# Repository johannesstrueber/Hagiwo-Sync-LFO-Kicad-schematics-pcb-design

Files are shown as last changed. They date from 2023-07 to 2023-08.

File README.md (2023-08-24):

# HAGIWO's SYNC LFO Eurorack Module<br/> Work in Progress Schematics, PCBs, and Design Files 

In this repository, I digitalized HAGIWOs sketched schematics in Kicad and then created PCBs for the circuit and a front panel. I also created two design files. The first is for matching the drill holes of the panel with the placed components. The second is for labeling the components on the silkscreen layer of the panel.

***This is a work-in-progress project. Actually, this is my first layout. Take nothing for granted. The second revision is produced.*** 
<br/>
<br/>
**TODO** <br/>
<ul>
<li>Physical solution for wrong pot direction (currently software solution)</li>
<li>code for second inverted output (is in WIP status)</li>
<li>GND planes</li>
</ul>
<br/>

**Here are the in- and outputs. To get a idea of the module**
- Knob 1: AMP – amplifier control. The output voltage is set between 0 and 5 volts. 
- Knob 2: PHASE – phase control sets the phase
- Knob 3: waveform control 
- Knob 4: MOD – internal modulation, creates complex waveforms 
- Input 1:  CLK – clock in
- Output 1: OUT – output
- Output 2: INV – inverted output
<br/>

**KICAD Notes**
 - design_placement.svg is placed on layer USER 8
 - circuit layout is generated by the freerouting plugin
<br/>

**BOM**
|ID |Identifier |Footprint |Amount|Description |
|---|---|---|---|---|
|1  |D4,D3 |LED_D3.0mm |2 |LED |
|2  |RV3-FORM1,RV2-PHASE1,RV4-MOD1,RV1-AMP1|Potentiometer_Alps_RK09K_Single_Vertical |4 |R_Potentiometer_US|
|3  |J1 |Jack_3.5mm_QingPu_WQP-PJ398SM_Vertical_CircularHoles|1 |CLOCK IN |
|4  |J3 |Jack_3.5mm_QingPu_WQP-PJ398SM_Vertical_CircularHoles|1 |INV |
|5  |J2 |Jack_3.5mm_QingPu_WQP-PJ398SM_Vertical_CircularHoles|1 |OUT |
|6  |R10,R4,R6,R7,R1,R5 |R_Axial_DIN0204_L3.6mm_D1.6mm_P2.54mm_Vertical |6 |R 470 |
|7  |C4,C1,C3,C2 |C_Disc_D4.3mm_W1.9mm_P5.00mm |4 |C 220pF |
|8  |D2,D1 |D_DO-35_SOD27_P7.62mm_Horizontal |2 |BAT43 |
|9  |R9,R8 |R_Axial_DIN0204_L3.6mm_D1.6mm_P2.54mm_Vertical |2 |R 33K |
|10 |J4 |IDC-Header_2x05_P2.54mm_Vertical |1 |Connector_02x05 |
|11 |R3 |R_Axial_DIN0204_L3.6mm_D1.6mm_P2.54mm_Vertical |1 |R 100K |
|12 |C6,C5 |CP_Radial_D5.0mm_P2.50mm |2 |C 4.7 µF |
|13 |A1 |Arduino_Nano |1 |Arduino_Nano |
|14 |R2 |R_Axial_DIN0204_L3.6mm_D1.6mm_P2.54mm_Vertical |1 |R 1K |

**CHANGELOG** <br/>
<br/>

**rev 0.2.1** <br/>
<ul>
<li>I adjusted the drilling diameter to 7.2mm to fit the threads of some potentiometers, e.g., t18. The previous front panel was made for rv09 potentiometers, which don't have a larger thread drilling.</li>
<li>the main pcb stays the same as 0.2.0</li>
</ul>
<br/>

**rev 0.2** <br/>
<ul>
<li> !!! changed pin order on connector </li>
<li> 10 pin connector instead of 16 pin</li>
<li> add missing 33k resistor for LED </li>
<li> resistors and capacitors now have values </li>
<li> larger gap setting for disc capacitors </li>
<li> code wrong direction potis</li>
<li> new design to match other upcoming modules </li>
<li> second output INV - inverted 
</ul>
<br/>

**rev 0.1** <br/>
<ul>
<li>first layout PRODUCED and working</li>
</ul>
<br/>

Hence, this is only trying to put HAGIWOs circuit into Kicad to create a PCB. You can find more information about the layout and functionality [ + here](https://note.com/solder_state/n/n4c600f2431c3) 
<br/>
<br/>

**Original Design and Code by HAGIWO** 
- [HAGIWO – note.com](https://note.com/solder_state)
- [HAGIWO – Twitter](https://twitter.com/HAGIWO1)
<br/>

**Fonts**
- [Rocko – Casady & Greene](https://moorstation.org/typoasis/designers/casady_greene/r_z.htm)
- [Tiny – Jack Halten Fahnestock](https://velvetyne.fr/fonts/tiny/)
<br/>

**Pictures of the produced rev 0.2**
<br/>
<br/>
front
<br/>
back
<br/>
side

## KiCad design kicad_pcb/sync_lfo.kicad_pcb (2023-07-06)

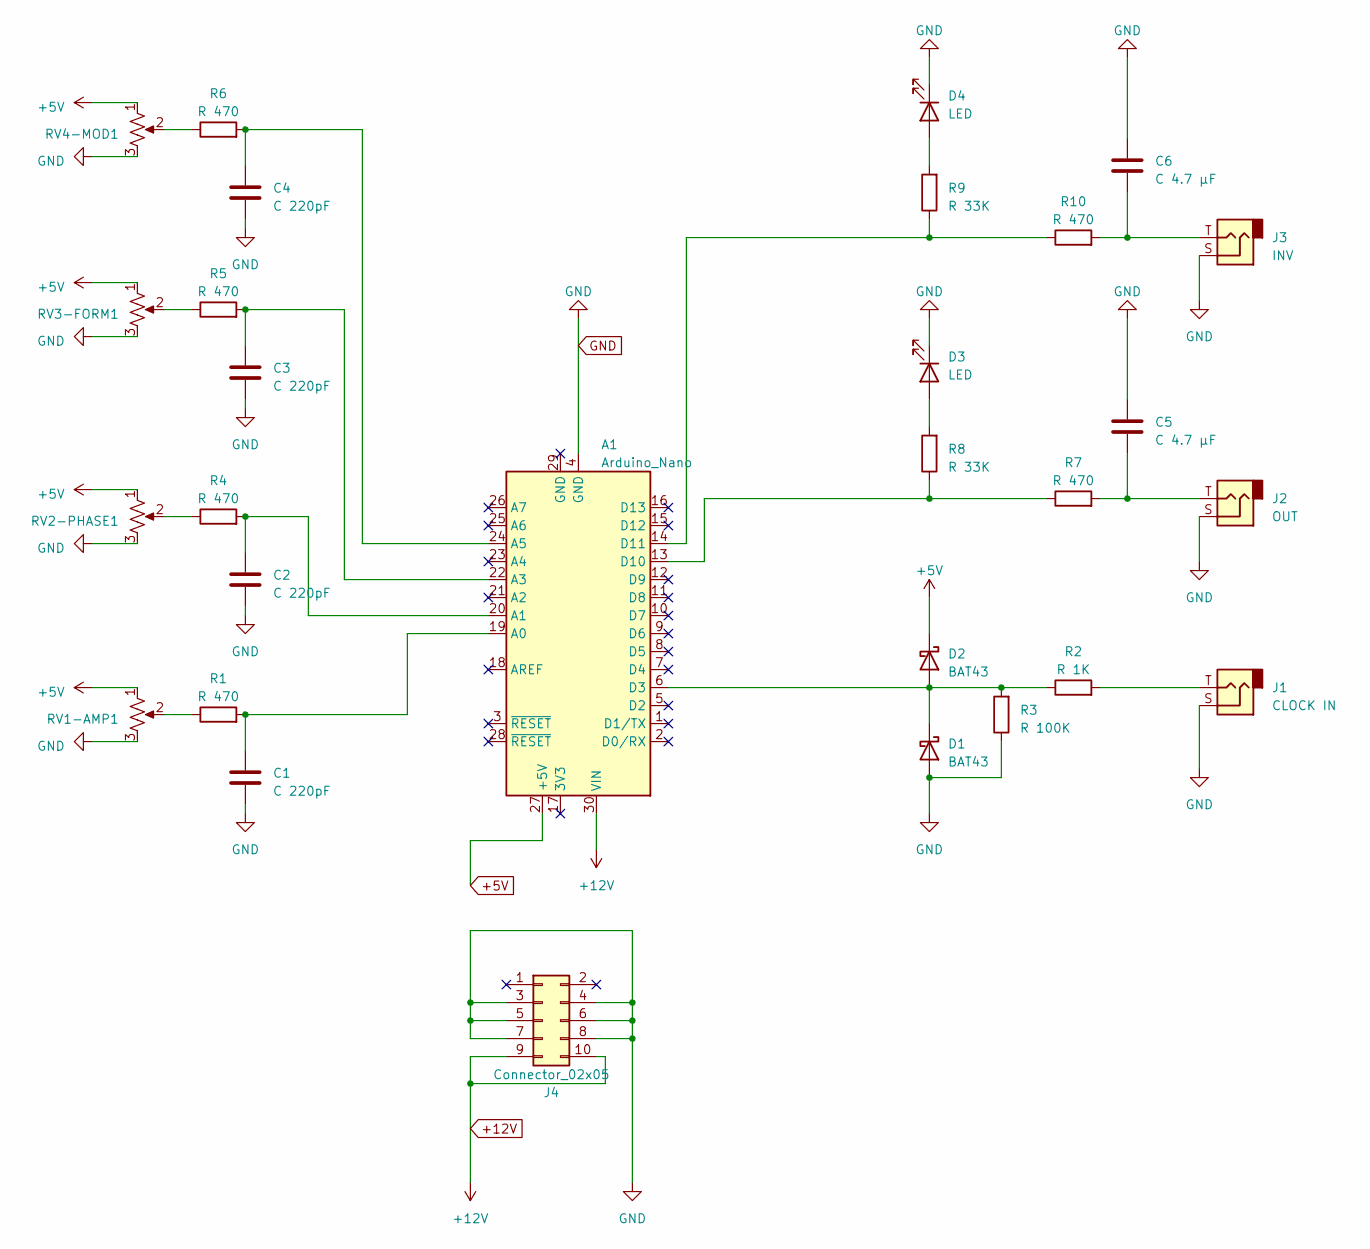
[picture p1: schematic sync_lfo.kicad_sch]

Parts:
A1: Arduino_Nano
C1, C2, C3, C4: C 220pF; C_Disc_D4.3mm_W1.9mm_P5.00mm
C5, C6: C 4.7 µF; C_Radial_D5.0mm_H11.0mm_P2.00mm
D1, D2: BAT43; D_DO-35_SOD27_P7.62mm_Horizontal
D3, D4: LED; LED_D3.0mm
J1: CLOCK IN; Jack_3.5mm_QingPu_WQP-PJ398SM_Vertical_CircularHoles
J2: OUT; Jack_3.5mm_QingPu_WQP-PJ398SM_Vertical_CircularHoles
J3: INV; Jack_3.5mm_QingPu_WQP-PJ398SM_Vertical_CircularHoles
J4: Connector_02x05; IDC-Header_2x05_P2.54mm_Vertical
R1, R4, R5, R6, R7, R10: R 470; R_Axial_DIN0204_L3.6mm_D1.6mm_P2.54mm_Vertical
R2: R 1K; R_Axial_DIN0204_L3.6mm_D1.6mm_P2.54mm_Vertical
R3: R 100K; R_Axial_DIN0204_L3.6mm_D1.6mm_P2.54mm_Vertical
R8, R9: R 33K; R_Axial_DIN0204_L3.6mm_D1.6mm_P2.54mm_Vertical
RV1-AMP1, RV2-PHASE1, RV3-FORM1, RV4-MOD1: R_Potentiometer_US; Potentiometer_Alps_RK09K_Single_Vertical

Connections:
+5V: A1.27 (+5V), D2.1 (K), RV1-AMP1.1, RV2-PHASE1.1, RV3-FORM1.1, RV4-MOD1.1
+12V: A1.30 (VIN), J4.9, J4.10
GND: A1.4 (GND), C1.2, C2.2, C3.2, C4.2, C5.1, C6.1, D1.2 (A), D3.1 (K), D4.1 (K), J1.S, J2.S, J3.S, J4.3, J4.4, J4.5, J4.6, J4.7, J4.8, R3.1, RV1-AMP1.3, RV2-PHASE1.3, RV3-FORM1.3, RV4-MOD1.3
unnamed: A1.19 (A0), C1.1, R1.2
unnamed: A1.20 (A1), C2.1, R4.2
unnamed: A1.22 (A3), C3.1, R5.2
unnamed: A1.24 (A5), C4.1, R6.2
unnamed: A1.6 (D3), D1.1 (K), D2.2 (A), R2.1, R3.2
unnamed: A1.13 (D10), R7.1, R8.1
unnamed: A1.14 (D11), R9.1, R10.1
unnamed: C5.2, J2.T, R7.2
unnamed: C6.2, J3.T, R10.2
unnamed: D3.2 (A), R8.2
unnamed: D4.2 (A), R9.2
unnamed: J1.T, R2.2
unnamed: R1.1, RV1-AMP1.2
unnamed: R4.1, RV2-PHASE1.2
unnamed: R5.1, RV3-FORM1.2
unnamed: R6.1, RV4-MOD1.2

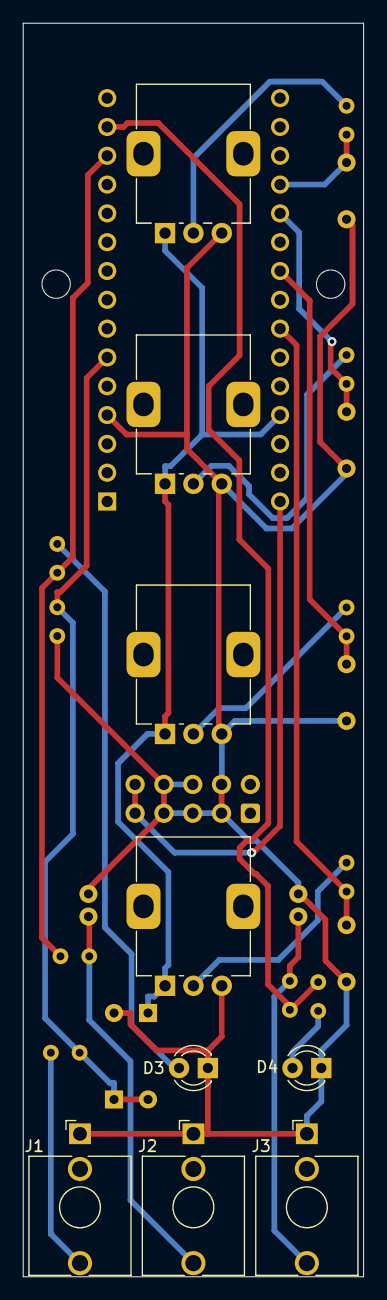
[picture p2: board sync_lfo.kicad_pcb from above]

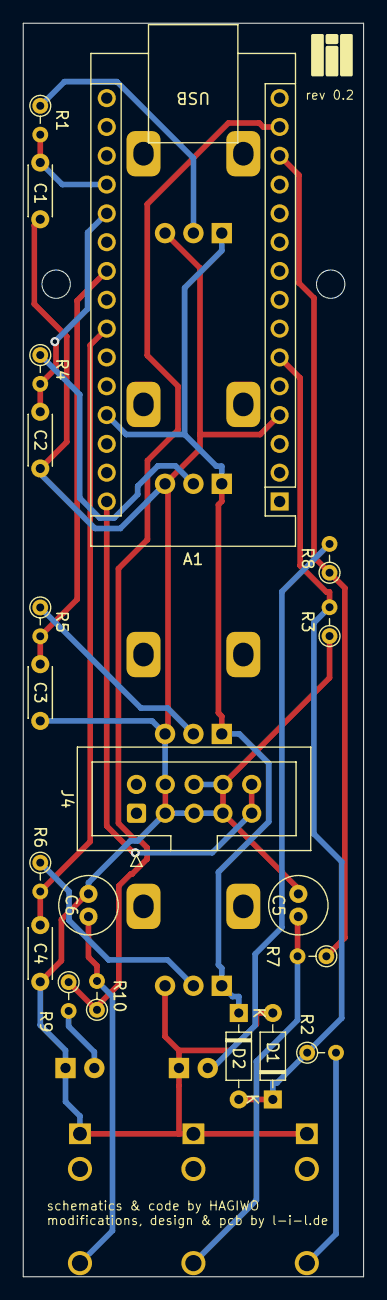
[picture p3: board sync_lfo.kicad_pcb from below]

Board: 2 copper layers, 30.0 x 110.5 mm, 30 parts (21 on the bottom side), 19 nets.

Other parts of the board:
HOLE RIGHT: MountingHole_2.5mm

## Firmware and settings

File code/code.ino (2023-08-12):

#include <FlexiTimer2.h>
#include <avr/io.h>

#define PWMInv 11
#define PWMOut 10
#define SyncIn 3
#define WaveformIn 3
#define AmpIn 0
#define PhaseIn 1
#define ModIn 5

unsigned int frq = 50000;
float duty = 0.5; // duty比率
int count = 0;

byte mode = 1; //
// 0=saw1
// 1=saw2
// 2=sine
// 3=tri
// 4=squ
// 5=random
// 6=steady

int set_freq = 1;  //
int freq_max = 30; // 外部クロック周期(*100usec)
int amp = 1;       // change pwm duty
float amp_rate = 1.0;
float amp_neg_rate = -1.0;
int phase = 1;
int mod = 0; // self modulation

bool ext_injudge = 0; // 0=use internal clock , 1 = use external clock
bool ext_pulse = 0;   // 0=no external in
bool old_ext_pulse = 0;
long ext_count = 0;
long ext_count_result = 0;
long old_ext_count_result = 0;
long ext_period = 0;
bool reset_count = 0;

// wave table
const static word saw1[1000] PROGMEM = {
    0, 1, 2, 3, 4, 5, 6, 7, 8, 9, 10, 11, 12, 13, 14, 15, 16, 17, 18, 19, 20, 21, 22, 23, 24, 25, 26, 27, 28, 29, 30, 31, 32, 33, 34, 35, 36, 37, 38, 39, 40, 41, 42, 43, 44, 45, 46, 47, 48, 49, 50, 51, 52, 53, 54, 55, 56, 57, 58, 59, 60, 61, 62, 63, 64, 65, 66, 67, 68, 69, 70, 71, 72, 73, 74, 75, 76, 77, 78, 79, 80, 81, 82, 83, 84, 85, 86, 87, 88, 89, 90, 91, 92, 93, 94, 95, 96, 97, 98, 99, 100, 101, 102, 103, 104, 105, 106, 107, 108, 109, 110, 111, 112, 113, 114, 115, 116, 117, 118, 119, 120, 121, 122, 123, 124, 125, 126, 127, 128, 129, 130, 131, 132, 133, 134, 135, 136, 137, 138, 139, 140, 141, 142, 143, 144, 145, 146, 147, 148, 149, 150, 151, 152, 153, 154, 155, 156, 157, 158, 159, 160, 161, 162, 163, 164, 165, 166, 167, 168, 169, 170, 171, 172, 173, 174, 175, 176, 177, 178, 179, 180, 181, 182, 183, 184, 185, 186, 187, 188, 189, 190, 191, 192, 193, 194, 195, 196, 197, 198, 199, 200, 201, 202, 203, 204, 205, 206, 207, 208, 209, 210, 211, 212, 213, 214, 215, 216, 217, 218, 219, 220, 221, 222, 223, 224, 225, 226, 227, 228, 229, 230, 231, 232, 233, 234, 235, 236, 237, 238, 239, 240, 241, 242, 243, 244, 245, 246, 247, 248, 249, 250, 251, 252, 253, 254, 255, 256, 257, 258, 259, 260, 261, 262, 263, 264, 265, 266, 267, 268, 269, 270, 271, 272, 273, 274, 275, 276, 277, 278, 279, 280, 281, 282, 283, 284, 285, 286, 287, 288, 289, 290, 291, 292, 293, 294, 295, 296, 297, 298, 299, 300, 301, 302, 303, 304, 305, 306, 307, 308, 309, 310, 311, 312, 313, 314, 315, 316, 317, 318, 319, 320, 321, 322, 323, 324, 325, 326, 327, 328, 329, 330, 331, 332, 333, 334, 335, 336, 337, 338, 339, 340, 341, 342, 343, 344, 345, 346, 347, 348, 349, 350, 351, 352, 353, 354, 355, 356, 357, 358, 359, 360, 361, 362, 363, 364, 365, 366, 367, 368, 369, 370, 371, 372, 373, 374, 375, 376, 377, 378, 379, 380, 381, 382, 383, 384, 385, 386, 387, 388, 389, 390, 391, 392, 393, 394, 395, 396, 397, 398, 399, 400, 401, 402, 403, 404, 405, 406, 407, 408, 409, 410, 411, 412, 413, 414, 415, 416, 417, 418, 419, 420, 421, 422, 423, 424, 425, 426, 427, 428, 429, 430, 431, 432, 433, 434, 435, 436, 437, 438, 439, 440, 441, 442, 443, 444, 445, 446, 447, 448, 449, 450, 451, 452, 453, 454, 455, 456, 457, 458, 459, 460, 461, 462, 463, 464, 465, 466, 467, 468, 469, 470, 471, 472, 473, 474, 475, 476, 477, 478, 479, 480, 481, 482, 483, 484, 485, 486, 487, 488, 489, 490, 491, 492, 493, 494, 495, 496, 497, 498, 499, 500, 501, 502, 503, 504, 505, 506, 507, 508, 509, 510, 511, 512, 513, 514, 515, 516, 517, 518, 519, 520, 521, 522, 523, 524, 525, 526, 527, 528, 529, 530, 531, 532, 533, 534, 535, 536, 537, 538, 539, 540, 541, 542, 543, 544, 545, 546, 547, 548, 549, 550, 551, 552, 553, 554, 555, 556, 557, 558, 559, 560, 561, 562, 563, 564, 565, 566, 567, 568, 569, 570, 571, 572, 573, 574, 575, 576, 577, 578, 579, 580, 581, 582, 583, 584, 585, 586, 587, 588, 589, 590, 591, 592, 593, 594, 595, 596, 597, 598, 599, 600, 601, 602, 603, 604, 605, 606, 607, 608, 609, 610, 611, 612, 613, 614, 615, 616, 617, 618, 619, 620, 621, 622, 623, 624, 625, 626, 627, 628, 629, 630, 631, 632, 633, 634, 635, 636, 637, 638, 639, 640, 641, 642, 643, 644, 645, 646, 647, 648, 649, 650, 651, 652, 653, 654, 655, 656, 657, 658, 659, 660, 661, 662, 663, 664, 665, 666, 667, 668, 669, 670, 671, 672, 673, 674, 675, 676, 677, 678, 679, 680, 681, 682, 683, 684, 685, 686, 687, 688, 689, 690, 691, 692, 693, 694, 695, 696, 697, 698, 699, 700, 701, 702, 703, 704, 705, 706, 707, 708, 709, 710, 711, 712, 713, 714, 715, 716, 717, 718, 719, 720, 721, 722, 723, 724, 725, 726, 727, 728, 729, 730, 731, 732, 733, 734, 735, 736, 737, 738, 739, 740, 741, 742, 743, 744, 745, 746, 747, 748, 749, 750, 751, 752, 753, 754, 755, 756, 757, 758, 759, 760, 761, 762, 763, 764, 765, 766, 767, 768, 769, 770, 771, 772, 773, 774, 775, 776, 777, 778, 779, 780, 781, 782, 783, 784, 785, 786, 787, 788, 789, 790, 791, 792, 793, 794, 795, 796, 797, 798, 799, 800, 801, 802, 803, 804, 805, 806, 807, 808, 809, 810, 811, 812, 813, 814, 815, 816, 817, 818, 819, 820, 821, 822, 823, 824, 825, 826, 827, 828, 829, 830, 831, 832, 833, 834, 835, 836, 837, 838, 839, 840, 841, 842, 843, 844, 845, 846, 847, 848, 849, 850, 851, 852, 853, 854, 855, 856, 857, 858, 859, 860, 861, 862, 863, 864, 865, 866, 867, 868, 869, 870, 871, 872, 873, 874, 875, 876, 877, 878, 879, 880, 881, 882, 883, 884, 885, 886, 887, 888, 889, 890, 891, 892, 893, 894, 895, 896, 897, 898, 899, 900, 901, 902, 903, 904, 905, 906, 907, 908, 909, 910, 911, 912, 913, 914, 915, 916, 917, 918, 919, 920, 921, 922, 923, 924, 925, 926, 927, 928, 929, 930, 931, 932, 933, 934, 935, 936, 937, 938, 939, 940, 941, 942, 943, 944, 945, 946, 947, 948, 949, 950, 951, 952, 953, 954, 955, 956, 957, 958, 959, 960, 961, 962, 963, 964, 965, 966, 967, 968, 969, 970, 971, 972, 973, 974, 975, 976, 977, 978, 979, 980, 981, 982, 983, 984, 985, 986, 987, 988, 989, 990, 991, 992, 993, 994, 995, 996, 997, 998, 999};
const static word saw2[1000] PROGMEM = {
    999, 998, 997, 996, 995, 994, 993, 992, 991, 990, 989, 988, 987, 986, 985, 984, 983, 982, 981, 980, 979, 978, 977, 976, 975, 974, 973, 972, 971, 970, 969, 968, 967, 966, 965, 964, 963, 962, 961, 960, 959, 958, 957, 956, 955, 954, 953, 952, 951, 950, 949, 948, 947, 946, 945, 944, 943, 942, 941, 940, 939, 938, 937, 936, 935, 934, 933, 932, 931, 930, 929, 928, 927, 926, 925, 924, 923, 922, 921, 920, 919, 918, 917, 916, 915, 914, 913, 912, 911, 910, 909, 908, 907, 906, 905, 904, 903, 902, 901, 900, 899, 898, 897, 896, 895, 894, 893, 892, 891, 890, 889, 888, 887, 886, 885, 884, 883, 882, 881, 880, 879, 878, 877, 876, 875, 874, 873, 872, 871, 870, 869, 868, 867, 866, 865, 864, 863, 862, 861, 860, 859, 858, 857, 856, 855, 854, 853, 852, 851, 850, 849, 848, 847, 846, 845, 844, 843, 842, 841, 840, 839, 838, 837, 836, 835, 834, 833, 832, 831, 830, 829, 828, 827, 826, 825, 824, 823, 822, 821, 820, 819, 818, 817, 816, 815, 814, 813, 812, 811, 810, 809, 808, 807, 806, 805, 804, 803, 802, 801, 800, 799, 798, 797, 796, 795, 794, 793, 792, 791, 790, 789, 788, 787, 786, 785, 784, 783, 782, 781, 780, 779, 778, 777, 776, 775, 774, 773, 772, 771, 770, 769, 768, 767, 766, 765, 764, 763, 762, 761, 760, 759, 758, 757, 756, 755, 754, 753, 752, 751, 750, 749, 748, 747, 746, 745, 744, 743, 742, 741, 740, 739, 738, 737, 736, 735, 734, 733, 732, 731, 730, 729, 728, 727, 726, 725, 724, 723, 722, 721, 720, 719, 718, 717, 716, 715, 714, 713, 712, 711, 710, 709, 708, 707, 706, 705, 704, 703, 702, 701, 700, 699, 698, 697, 696, 695, 694, 693, 692, 691, 690, 689, 688, 687, 686, 685, 684, 683, 682, 681, 680, 679, 678, 677, 676, 675, 674, 673, 672, 671, 670, 669, 668, 667, 666, 665, 664, 663, 662, 661, 660, 659, 658, 657, 656, 655, 654, 653, 652, 651, 650, 649, 648, 647, 646, 645, 644, 643, 642, 641, 640, 639, 638, 637, 636, 635, 634, 633, 632, 631, 630, 629, 628, 627, 626, 625, 624, 623, 622, 621, 620, 619, 618, 617, 616, 615, 614, 613, 612, 611, 610, 609, 608, 607, 606, 605, 604, 603, 602, 601, 600, 599, 598, 597, 596, 595, 594, 593, 592, 591, 590, 589, 588, 587, 586, 585, 584, 583, 582, 581, 580, 579, 578, 577, 576, 575, 574, 573, 572, 571, 570, 569, 568, 567, 566, 565, 564, 563, 562, 561, 560, 559, 558, 557, 556, 555, 554, 553, 552, 551, 550, 549, 548, 547, 546, 545, 544, 543, 542, 541, 540, 539, 538, 537, 536, 535, 534, 533, 532, 531, 530, 529, 528, 527, 526, 525, 524, 523, 522, 521, 520, 519, 518, 517, 516, 515, 514, 513, 512, 511, 510, 509, 508, 507, 506, 505, 504, 503, 502, 501, 500, 499, 498, 497, 496, 495, 494, 493, 492, 491, 490, 489, 488, 487, 486, 485, 484, 483, 482, 481, 480, 479, 478, 477, 476, 475, 474, 473, 472, 471, 470, 469, 468, 467, 466, 465, 464, 463, 462, 461, 460, 459, 458, 457, 456, 455, 454, 453, 452, 451, 450, 449, 448, 447, 446, 445, 444, 443, 442, 441, 440, 439, 438, 437, 436, 435, 434, 433, 432, 431, 430, 429, 428, 427, 426, 425, 424, 423, 422, 421, 420, 419, 418, 417, 416, 415, 414, 413, 412, 411, 410, 409, 408, 407, 406, 405, 404, 403, 402, 401, 400, 399, 398, 397, 396, 395, 394, 393, 392, 391, 390, 389, 388, 387, 386, 385, 384, 383, 382, 381, 380, 379, 378, 377, 376, 375, 374, 373, 372, 371, 370, 369, 368, 367, 366, 365, 364, 363, 362, 361, 360, 359, 358, 357, 356, 355, 354, 353, 352, 351, 350, 349, 348, 347, 346, 345, 344, 343, 342, 341, 340, 339, 338, 337, 336, 335, 334, 333, 332, 331, 330, 329, 328, 327, 326, 325, 324, 323, 322, 321, 320, 319, 318, 317, 316, 315, 314, 313, 312, 311, 310, 309, 308, 307, 306, 305, 304, 303, 302, 301, 300, 299, 298, 297, 296, 295, 294, 293, 292, 291, 290, 289, 288, 287, 286, 285, 284, 283, 282, 281, 280, 279, 278, 277, 276, 275, 274, 273, 272, 271, 270, 269, 268, 267, 266, 265, 264, 263, 262, 261, 260, 259, 258, 257, 256, 255, 254, 253, 252, 251, 250, 249, 248, 247, 246, 245, 244, 243, 242, 241, 240, 239, 238, 237, 236, 235, 234, 233, 232, 231, 230, 229, 228, 227, 226, 225, 224, 223, 222, 221, 220, 219, 218, 217, 216, 215, 214, 213, 212, 211, 210, 209, 208, 207, 206, 205, 204, 203, 202, 201, 200, 199, 198, 197, 196, 195, 194, 193, 192, 191, 190, 189, 188, 187, 186, 185, 184, 183, 182, 181, 180, 179, 178, 177, 176, 175, 174, 173, 172, 171, 170, 169, 168, 167, 166, 165, 164, 163, 162, 161, 160, 159, 158, 157, 156, 155, 154, 153, 152, 151, 150, 149, 148, 147, 146, 145, 144, 143, 142, 141, 140, 139, 138, 137, 136, 135, 134, 133, 132, 131, 130, 129, 128, 127, 126, 125, 124, 123, 122, 121, 120, 119, 118, 117, 116, 115, 114, 113, 112, 111, 110, 109, 108, 107, 106, 105, 104, 103, 102, 101, 100, 99, 98, 97, 96, 95, 94, 93, 92, 91, 90, 89, 88, 87, 86, 85, 84, 83, 82, 81, 80, 79, 78, 77, 76, 75, 74, 73, 72, 71, 70, 69, 68, 67, 66, 65, 64, 63, 62, 61, 60, 59, 58, 57, 56, 55, 54, 53, 52, 51, 50, 49, 48, 47, 46, 45, 44, 43, 42, 41, 40, 39, 38, 37, 36, 35, 34, 33, 32, 31, 30, 29, 28, 27, 26, 25, 24, 23, 22, 21, 20, 19, 18, 17, 16, 15, 14, 13, 12, 11, 10, 9, 8, 7, 6, 5, 4, 3, 2, 1, 0};
const static word sine[1000] PROGMEM = {
    500, 500, 500, 500, 510, 510, 510, 520, 520, 520, 530, 530, 530, 540, 540, 540, 550, 550, 550, 550, 560, 560, 560, 570, 570, 570, 580, 580, 580, 590, 590, 590, 590, 600, 600, 600, 610, 610, 610, 620, 620, 620, 630, 630, 630, 630, 640, 640, 640, 650, 650, 650, 660, 660, 660, 660, 670, 670, 670, 680, 680, 680, 680, 690, 690, 690, 700, 700, 700, 710, 710, 710, 710, 720, 720, 720, 720, 730, 730, 730, 740, 740, 740, 740, 750, 750, 750, 750, 760, 760, 760, 770, 770, 770, 770, 780, 780, 780, 780, 790, 790, 790, 790, 800, 800, 800, 800, 810, 810, 810, 810, 820, 820, 820, 820, 830, 830, 830, 830, 830, 840, 840, 840, 840, 850, 850, 850, 850, 860, 860, 860, 860, 860, 870, 870, 870, 870, 870, 880, 880, 880, 880, 880, 890, 890, 890, 890, 890, 900, 900, 900, 900, 900, 900, 910, 910, 910, 910, 910, 920, 920, 920, 920, 920, 920, 930, 930, 930, 930, 930, 930, 930, 940, 940, 940, 940, 940, 940, 940, 950, 950, 950, 950, 950, 950, 950, 960, 960, 960, 960, 960, 960, 960, 960, 960, 970, 970, 970, 970, 970, 970, 970, 970, 970, 970, 980, 980, 980, 980, 980, 980, 980, 980, 980, 980, 980, 980, 980, 980, 990, 990, 990, 990, 990, 990, 990, 990, 990, 990, 990, 990, 990, 990, 990, 990, 990, 990, 990, 990, 990, 990, 990, 990, 990, 990, 990, 990, 990, 990, 990, 1000, 990, 990, 990, 990, 990, 990, 990, 990, 990, 990, 990, 990, 990, 990, 990, 990, 990, 990, 990, 990, 990, 990, 990, 990, 990, 990, 990, 990, 990, 990, 990, 980, 980, 980, 980, 980, 980, 980, 980, 980, 980, 980, 980, 980, 980, 970, 970, 970, 970, 970, 970, 970, 970, 970, 970, 960, 960, 960, 960, 960, 960, 960, 960, 960, 950, 950, 950, 950, 950, 950, 950, 940, 940, 940, 940, 940, 940, 940, 930, 930, 930, 930, 930, 930, 930, 920, 920, 920, 920, 920, 920, 910, 910, 910, 910, 910, 900, 900, 900, 900, 900, 900, 890, 890, 890, 890, 890, 880, 880, 880, 880, 880, 870, 870, 870, 870, 870, 860, 860, 860, 860, 860, 850, 850, 850, 850, 840, 840, 840, 840, 830, 830, 830, 830, 830, 820, 820, 820, 820, 810, 810, 810, 810, 800, 800, 800, 800, 790, 790, 790, 790, 780, 780, 780, 780, 770, 770, 770, 770, 760, 760, 760, 750, 750, 750, 750, 740, 740, 740, 740, 730, 730, 730, 720, 720, 720, 720, 710, 710, 710, 710, 700, 700, 700, 690, 690, 690, 680, 680, 680, 680, 670, 670, 670, 660, 660, 660, 660, 650, 650, 650, 640, 640, 640, 630, 630, 630, 630, 620, 620, 620, 610, 610, 610, 600, 600, 600, 590, 590, 590, 590, 580, 580, 580, 570, 570, 570, 560, 560, 560, 550, 550, 550, 550, 540, 540, 540, 530, 530, 530, 520, 520, 520, 510, 510, 510, 500, 500, 500, 500, 490, 490, 490, 480, 480, 480, 470, 470, 470, 460, 460, 460, 450, 450, 450, 440, 440, 440, 440, 430, 430, 430, 420, 420, 420, 410, 410, 410, 400, 400, 400, 400, 390, 390, 390, 380, 380, 380, 370, 370, 370, 360, 360, 360, 360, 350, 350, 350, 340, 340, 340, 330, 330, 330, 330, 320, 320, 320, 310, 310, 310, 310, 300, 300, 300, 290, 290, 290, 280, 280, 280, 280, 270, 270, 270, 270, 260, 260, 260, 250, 250, 250, 250, 240, 240, 240, 240, 230, 230, 230, 220, 220, 220, 220, 210, 210, 210, 210, 200, 200, 200, 200, 190, 190, 190, 190, 180, 180, 180, 180, 170, 170, 170, 170, 160, 160, 160, 160, 160, 150, 150, 150, 150, 140, 140, 140, 140, 130, 130, 130, 130, 130, 120, 120, 120, 120, 120, 110, 110, 110, 110, 110, 100, 100, 100, 100, 100, 90, 90, 90, 90, 90, 90, 80, 80, 80, 80, 80, 70, 70, 70, 70, 70, 70, 60, 60, 60, 60, 60, 60, 60, 50, 50, 50, 50, 50, 50, 50, 40, 40, 40, 40, 40, 40, 40, 30, 30, 30, 30, 30, 30, 30, 30, 30, 20, 20, 20, 20, 20, 20, 20, 20, 20, 20, 10, 10, 10, 10, 10, 10, 10, 10, 10, 10, 10, 10, 10, 10, 0, 0, 0, 0, 0, 0, 0, 0, 0, 0, 0, 0, 0, 0, 0, 0, 0, 0, 0, 0, 0, 0, 0, 0, 0, 0, 0, 0, 0, 0, 0, 0, 0, 0, 0, 0, 0, 0, 0, 0, 0, 0, 0, 0, 0, 0, 0, 0, 0, 0, 0, 0, 0, 0, 0, 0, 0, 0, 0, 0, 0, 0, 0, 10, 10, 10, 10, 10, 10, 10, 10, 10, 10, 10, 10, 10, 10, 20, 20, 20, 20, 20, 20, 20, 20, 20, 20, 30, 30, 30, 30, 30, 30, 30, 30, 30, 40, 40, 40, 40, 40, 40, 40, 50, 50, 50, 50, 50, 50, 50, 60, 60, 60, 60, 60, 60, 60, 70, 70, 70, 70, 70, 70, 80, 80, 80, 80, 80, 90, 90, 90, 90, 90, 90, 100, 100, 100, 100, 100, 110, 110, 110, 110, 110, 120, 120, 120, 120, 120, 130, 130, 130, 130, 130, 140, 140, 140, 140, 150, 150, 150, 150, 160, 160, 160, 160, 160, 170, 170, 170, 170, 180, 180, 180, 180, 190, 190, 190, 190, 200, 200, 200, 200, 210, 210, 210, 210, 220, 220, 220, 220, 230, 230, 230, 240, 240, 240, 240, 250, 250, 250, 250, 260, 260, 260, 270, 270, 270, 270, 280, 280, 280, 280, 290, 290, 290, 300, 300, 300, 310, 310, 310, 310, 320, 320, 320, 330, 330, 330, 330, 340, 340, 340, 350, 350, 350, 360, 360, 360, 360, 370, 370, 370, 380, 380, 380, 390, 390, 390, 400, 400, 400, 400, 410, 410, 410, 420, 420, 420, 430, 430, 430, 440, 440, 440, 440, 450, 450, 450, 460, 460, 460, 470, 470, 470, 480, 480, 480, 490, 490, 490};
const static word tri[1000] PROGMEM = {
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
void loop()
{
  old_ext_pulse = ext_pulse;
  ext_pulse = digitalRead(3);

  //------------wave select-------------------------------
  int WF = analogRead(WaveformIn);
  if (WF < 31)
  {
    mode = 5;
  }
  else if (WF >= 31 && WF < 155)
  {
    mode = 4;
  }
  else if (WF >= 155 && WF < 352)
  {
    mode = 3;
  }
  else if (WF >= 352 && WF < 571)
  {
    mode = 2;
  }
  else if (WF >= 571 && WF < 771)
  {
    mode = 1;
  }
  else if (WF >= 771 && WF < 939)
  {
    mode = 0;
  }
  else if (WF >= 939)
  {
    mode = 6;
  }

  //------------phase and internal clock set-------------------------------
  if (ext_injudge == 0)
  { // use internal clock , phase function off
    phase = 0;
    // freq_max = 1 + (analogRead(1)) / 5;
    freq_max = 1 + 0.0007 * analogRead(1) * analogRead(1);
    if (freq_max > 1000)
    {
      freq_max = 1000;
    }
    else if (freq_max < 1)
    {
      freq_max = 1;
    }
  }

  else if (ext_injudge == 1)
  { // use external clock , phase function on
    phase = map(analogRead(1), 0, 1023, 0, 999);
  }

  //------------selc modulation-------------------------------
  int MD = analogRead(ModIn);
  if (MD < 31)
  {
    mod = 6;
  }
  else if (MD >= 31 && MD < 155)
  {
    mod = 5;
  }
  else if (MD >= 155 && MD < 352)
  {
    mod = 4;
  }
  else if (MD >= 352 && MD < 571)
  {
    mod = 3;
  }
  else if (MD >= 571 && MD < 771)
  {
    mod = 2;
  }
  else if (MD >= 771 && MD < 939)
  {
    mod = 1;
  }
  else if (MD >= 939)
  {
    mod = 0;
  }

  switch (mod)
  {
  case 0:
    break;

  case 1:
    phase = phase + (pgm_read_word(&(saw1[count])));
    break;

  case 2:
    phase = phase + (pgm_read_word(&(saw2[count])));
    break;

  case 3:
    phase = phase + (pgm_read_word(&(sine[count])));
    break;

  case 4:
    phase = phase + (pgm_read_word(&(tri[count])));
    break;

  case 5:
    phase = phase + (pgm_read_word(&(squ[count])));
    break;

  case 6:
    phase = phase + (pgm_read_word(&(saw1[random(1, 1000)])));
    break;
  }

  //--------------amp set----------------
  amp = analogRead(0);
  amp = map(amp, 0, 1023, 1, 100);
  amp_rate = ((float)amp / 100 - 1) * -1;
  amp_neg_rate = (float)amp / 100 - 1;

  //------------external in judge-------------------------------
  if (ext_count > 160000)
  { // no external signal during 8 sec
    ext_injudge = 0;
  }
  else
  {
    ext_injudge = 1;
  }

  //----------clock setting-------------

  if (ext_pulse == 1 && old_ext_pulse == 0)
  {
    old_ext_count_result = ext_count_result; // twice pulse average
    ext_count_result = ext_count;
    ext_period = (old_ext_count_result + ext_count_result) / 1960;
    freq_max = ext_period;
  }

  if (old_ext_pulse == 0 && ext_pulse == 1)
  { // 外部入力が有→無のとき
    ext_count = 0;
    count = 0;
  }
  // モード指定
  TCCR1A = 0b00100001;
  TCCR1B = 0b00000001; // 分周比1

  TCCR2A = 0b00100001;
  TCCR2B = 0b00000001; // 分周比1

  // TOP値指定
  // 8000000 / 1 / 160 = 50000
  // or 4900000 / 1 / 160 = 30625
  OCR1A = (unsigned int)(250);
  OCR1B = (unsigned int)(250 * duty * amp_rate);

  OCR2A = (unsigned int)(250);
  OCR2B = (unsigned int)(250 * duty * amp_neg_rate + 250);

  analogWrite(PWMOut, OCR1B);
  analogWrite(PWMInv, OCR2B);
}

void timer_count()
{

  ext_count++;
  set_freq++;

  if (set_freq >= freq_max)
  {
    set_freq = 0;

    count++;
    if (count + phase >= 1000 && mode != 5)
    {
      count = count - 1000;
    }

    switch (mode)
    {
    case 0:
      duty = (float)(pgm_read_word(&(saw1[count + phase]))) / 1000;
      break;

    case 1:
      duty = (float)(pgm_read_word(&(saw2[count + phase]))) / 1000;
      break;

    case 2:
      duty = (float)(pgm_read_word(&(sine[count + phase]))) / 1000;
      break;

    case 3:
      duty = (float)(pgm_read_word(&(tri[count + phase]))) / 1000;
      break;

    case 4:
      duty = (float)(pgm_read_word(&(squ[count + phase]))) / 1000;
      break;
    }

    // random
    if (mode == 5)
    {
      count++;
      if (count >= 250)
      {
        count = 0;
        duty = random(1, 1000);
        duty = duty / 1000;
      }
    }

    // steady
    if (mode == 6)
    {
      duty = 1;
    }
  }

  if (duty > 1)
  {
    duty = 1;
  }
  if (duty < 0)
  {
    duty = 0;
  }
}

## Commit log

2023-06-19 feat: :fire: remove unsused copper frontpanel
    [kicad_frontpanel.kicad_pcb]
2023-06-19 feat: :bookmark: rev 0.2 frontpanel
    [kicad_frontpanel.kicad_pcb]
2023-06-19 feat: :sparkles: rev 0.2 pcb and schematics
    [sync_lfo.kicad_pcb, sync_lfo.kicad_sch]
2023-06-25 feat: :sparkles: 10pin connector, drill holes, for distance, better routing
    [sync_lfo.kicad_pcb, sync_lfo.kicad_sch]
2023-07-03 feat: :lipstick: update design files, overall design system, clean placement file
    [kicad_frontpanel.kicad_pcb, sync_lfo.kicad_pcb]
2023-07-06 feat: :sparkles: inv output, new design, reposition
    [kicad_frontpanel.kicad_pcb, sync_lfo.kicad_pcb, sync_lfo.kicad_sch]
2023-07-27 feat: :sparkles: adjust potentiometer drillings to also fit potis with threads
    [kicad_frontpanel.kicad_pcb]
2023-07-27 feat: :sparkles: add invert output to code WIP
    [code.ino]
2023-08-12 feat: :bug: correct max voltage
    [code.ino]
2023-08-24 add BOM.md
